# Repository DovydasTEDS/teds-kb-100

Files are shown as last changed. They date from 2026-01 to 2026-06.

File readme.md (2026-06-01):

# TEDS KB 100  
  
A 100% ISO-105 Mechanical keyboard - custom PCB, custom case.
It has per-key rgb leds and a rotary encoder. The firmware is written in QMK.

## How to build

  Flash the RP2040 / pi pico devboard with the firmware by holding the boot button and then plugging it into a computer. Then drag the firmware into a drive that appears.  
  When assembling, make sure you solder all of the components to the PCB, but don't insert the switches. First attach the plate, then add the switches into the hotswap sockets, or solder them if you choose not to include them.  
  Then screw the plate to the base, and finally, screw the top. All screws / bolts should be M3. The shorter M3 screws attach the plate to the base while the longer screws attach the top to the bottom. The top plate is optional, and it should work without it.  

## Why did I make this project?  

  Most mechanical gaming keyboards are... mediocre. Firmware that sucks. Software that sucks more. And they all lack one feature or another.  
  And many mechanical keyboards focus on... 60% and TKL. I haven't seen as much focus on cusom 100% keyboards. This is why I decided to make one! (Also since I'm using a membrane keyboard currently...)

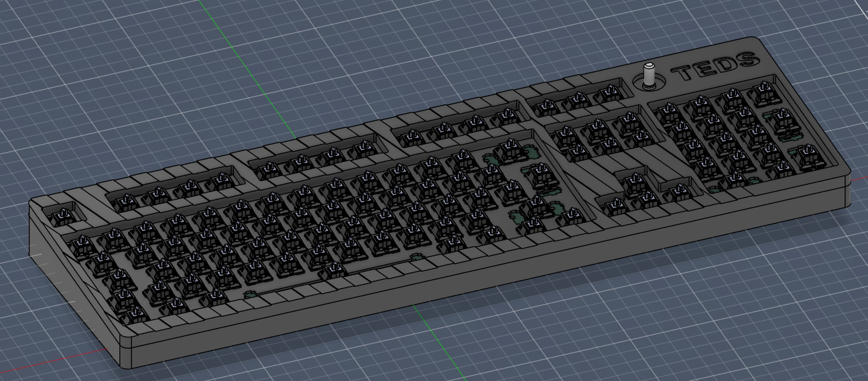
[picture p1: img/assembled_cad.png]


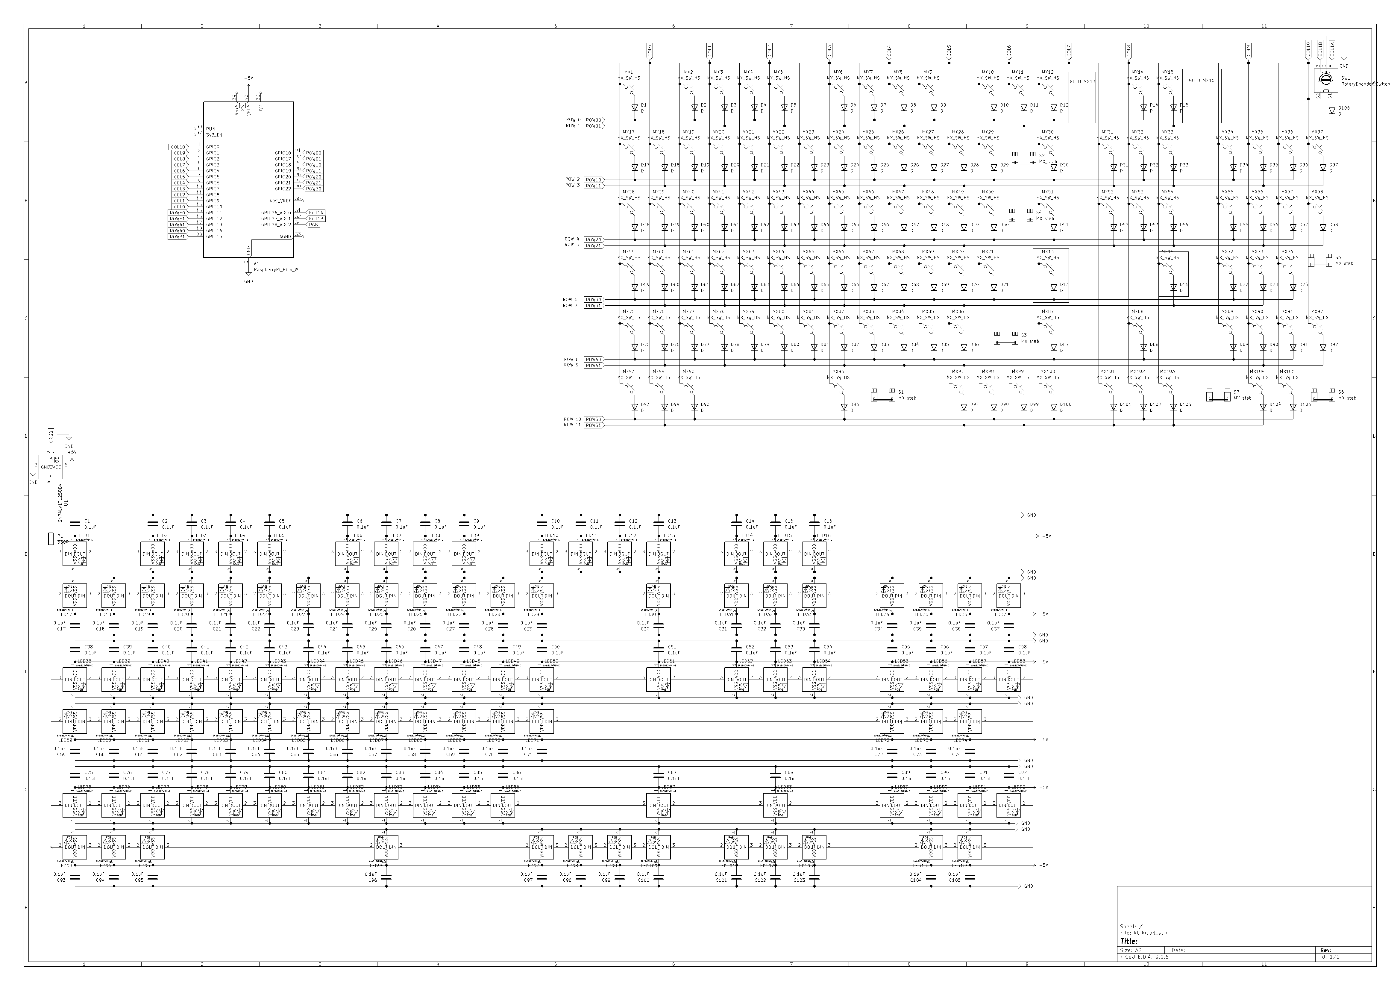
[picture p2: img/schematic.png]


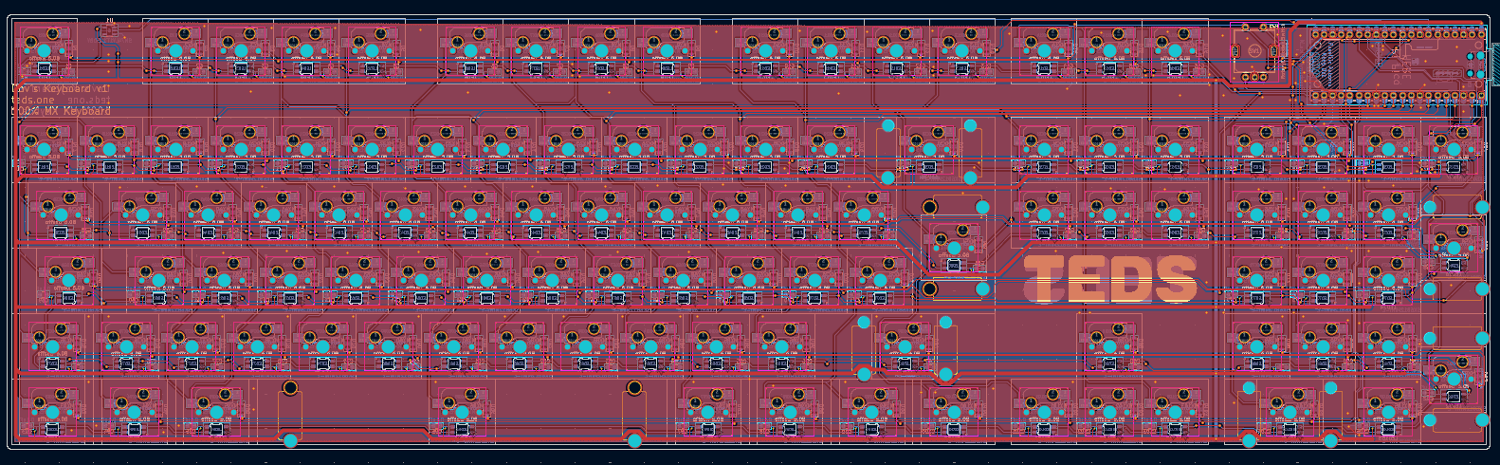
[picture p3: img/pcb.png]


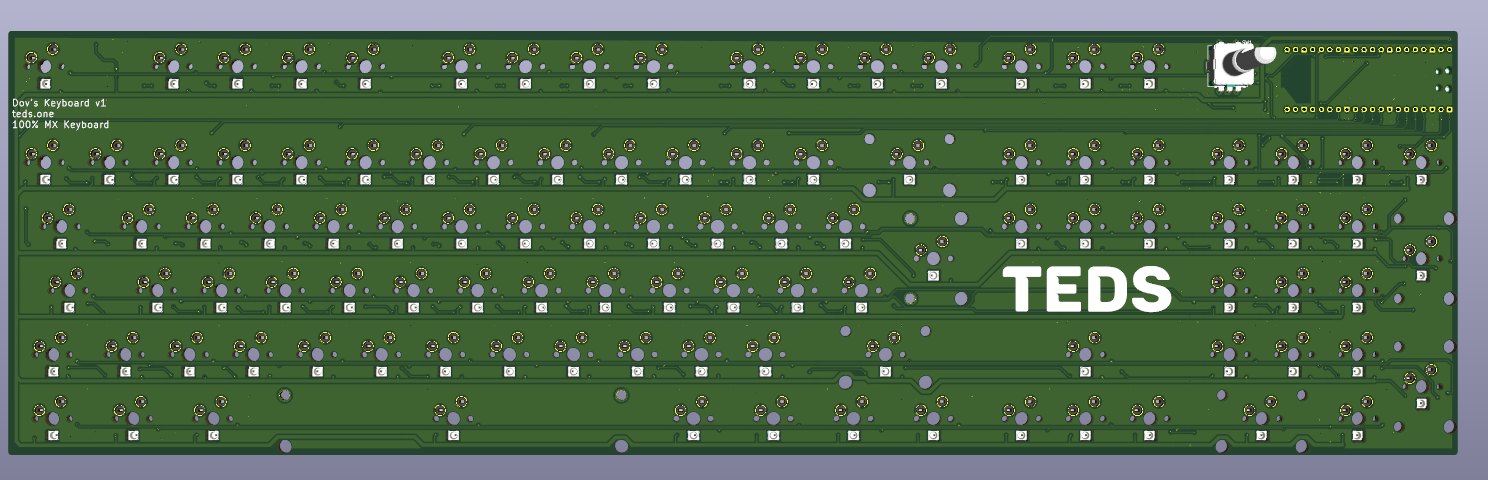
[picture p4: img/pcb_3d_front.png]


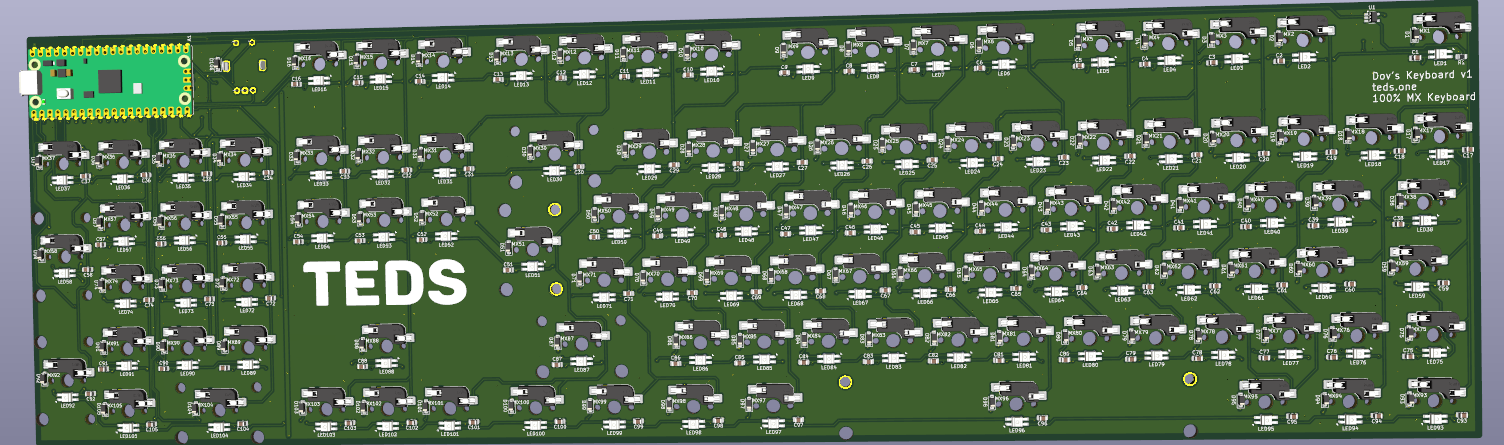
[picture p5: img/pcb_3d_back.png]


## Bill of Materials
  
|Item |Description |Quantity (no MOQ)|Amount (per quantity)|Quantity|Unit Price|Total Price|Running Total|URL |LCSC Part No|
|---|---|---|---|---|---|---|---|---|---|
|PCB |PCB (Minimum order of 5, includes $13.06 global direct line shipping, and $7.62 tax + duties)|1 |5 |1 |$45.68 |$45.68 |$45.68 |[JLCPCB](https://jlcpcb.com) | |
| | | | | | | | | | |
|LCSC |Total: 12.7692 + shipping fees | | | | | | | | |
|SK6812MINI-E |Backlight LEDs |105 |1 |105 |$0.07 |$7.27 |$52.95 |[C5149201](https://www.lcsc.com/product-detail/C5149201.html) |C5149201 |
|SN74LV1T125DBVR |Level Shifter |1 |1 |5 |$0.20 |$0.98 |$53.93 |[C473338](https://www.lcsc.com/product-detail/C473338.html) |C473338 |
|CC0805KRX7R9BB104 |100nF �10% 50V Ceramic Capacitor 0805 |105 |1 |200 |$0.01 |$1.30 |$55.23 |[C49678](https://www.lcsc.com/product-detail/C49678.html) |C49678 |
|1N4148W |Diodes Surface Mount SOD-123 |105 |1 |200 |$0.01 |$1.16 |$56.39 |[C917030](https://www.lcsc.com/product-detail/C917030.html) |C917030 |
|0805W8F3300T5E |330? �1% 125mW 0805 Thick Film Resisto |1 |1 |105 |$0.00 |$0.29 |$56.68 |[C17630](https://www.lcsc.com/product-detail/C17630.html) |C17630 |
|EC11E09244BS |Rotary Encoder EC11 |1 |1 |1 |$1.77 |$1.77 |$58.45 |[C470742](https://www.lcsc.com/product-detail/C470742.html) |C470742 |
| | | | | | | | | | |
|AliExpress |Total: 55.17 + shipping fees | | | | | | | | |
|Pi Pico Board |RP2040 Devboard / Pico Clone |1 |1 |1 |$2.73 |$2.73 |$61.18 |[AliExpress](https://www.aliexpress.com/item/1005007393927221.html)| |
|Hotswap MX Sockets|110x Kailh Hot-swappable PCB Socket Hot Plug |105 |110 |1 |$6.65 |$6.65 |$67.83 |[AliExpress](https://www.aliexpress.com/item/1005007232040760.html)| |
|Switches |Kailh Speed Sliver |105 |110 |1 |$19.41 |$19.41 |$87.24 |[AliExpress](https://www.aliexpress.com/item/1005003436102892.html)| |
|Keycaps |135 Keycaps Shine-through (Lucky Red colour) |105 |135 |1 |$13.54 |$13.54 |$100.78 |[AliExpress](https://www.aliexpress.com/item/1005010510805160.html)| |
|M3 Heatset Inserts|Length 3mm 50pcs,�M3(OD4.2mm) |18 |50 |1 |$1.87 |$1.87 |$102.65 |[AliExpress](https://www.aliexpress.com/item/1005003582355741.html)| |
|M3 Screws |M3 50pcs,�12mm |18 |50 |1 |$1.87 |$1.87 |$104.52 |[AliExpress](https://www.aliexpress.com/item/1005007264845313.html)| |
|Stabilisers |Durock Stabilisers V3 BS 7x2u 1x6.25u |1 |1 |1 |$6.74 |$6.74 |$111.26 |[AliExpress](https://www.aliexpress.com/item/1005006528731543.html)| |
|Encoder Knob |Red Enoder Knob |1 |1 |1 |$2.36 |$2.36 |$113.62 |[AliExpress](https://www.aliexpress.com/item/1005009263732468.html)| |
| | | | | | | | | | |
| | | | | | |Total: |$113.62 | | |

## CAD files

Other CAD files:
cad/step/Top.step
production/Bottom.step
cad/step/Plate.step
production/Top.step
cad/step/Bottom.step
production/Plate.step
cad/f3d/Assembled.f3z
cad/f3d/Bottom.f3d
cad/f3d/Plate.f3d
cad/f3d/Top.f3d

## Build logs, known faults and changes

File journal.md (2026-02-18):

<!--
  This journal is auto generated by Hack Club Blueprint.
-->

# 12/29/2025 - Layout + Switches  

_Time spent: 3.0h_  




First, I setup the required KiCad libraries / plugins. This involved installing the following repos:
[Zykrah's KiCad repository](https://raw.githubusercontent.com/zykrah/zykrah-kicad-repository/main/repository.json)
[ebastler KiCad repository](https://raw.githubusercontent.com/ebastler/ebastler-KiCad-repository/main/repository.json)

From these repos, I installed the marbastlib library and the KiCad KLE placer plugin.

I then started placing down the switch matrix (22 columns, 6 rows). I then deleted the switches that weren't used, or areas where a switch was larger (e.g. enter, shift). After that, I started placing the PCB. After updating from the schematic, I placed the first switch and diode down in their correct positions. Using the KLE auto placer plugin, I was able to easily replicate this and place all of the other switches down, with the diodes in the same position. I then placed all of the stabilisers for all of the switches that were 2u or larger.

Summary:  
- Setup the environment
- Created the schematic for the switch matrix
- Placed switches in ISO 105 key layout
- Placed stabilisers

Todo:
- Wire everything
- Add leds (per switch)  

# 1/10/2026 10 AM - Connected switches (Schematic)  

_Time spent: 0.5h_  



I connected all of the switches in the schematic in a matrix. I ended up with 6 rows and 20 columns. Unfortunately the pico only has 26 GPIO pins. I may need to use an IO expander.  

# 1/10/2026 3 PM - Duplex Matrix  

_Time spent: 1.0h_  



Instead of an IO expander, I decided to add a duplex matrix. This involved merging 2 pairs of columns, halving the number of columns needed, but doubling the rows needed. Overall, this saved pins. I was also able to move some of the switches which were in a column alone to free up a column. This should remove the need for an IO expander. I looked into IO expanders, but felt they were too undocumented, both in QMK and ZMK. I am also considering whether I should add a rotary encoder or an oled screen, since I will only have 2 free GPIO pins after I add the backlight / rgb lights.  

# 1/11/2026 10:04 PM - Added RGB  

_Time spent: 2.0h_  



I added the RGB leds (sk6812mini-e) to the schematic and wired them up. I used 0.1uF capacitors to reduce the power consumption and that it wouldn't overload the pi. I connected the 5v to the VBUS / USB 5v power. Hopefully it works. Also wasted a bit of time due to bad counting.   

# 1/11/2026 10:24 PM - Fixed Capacitors  

_Time spent: 0.5h_  



So turns out I don't know how capacitors work... At least I figured it out by doing some googling and wondering why mine looks very different to the others.  

# 1/12/2026 - Position all LEDs  

_Time spent: 2.0h_  



I positioned all of the SK6812MINI-E LEDs and started wiring up the switches. But guess who forgot the capacitors... me. Hopefully all of the traces arent in the way of the capacitors.  

# 1/14/2026 - Capacitors + Connect rows + Columns  

_Time spent: 2.0h_  



I connected all of the rows and columns together (duplex so 2x rows and half columns). I placed the capacitors after which was a bad idea, but in the end it worked out. It was a lot of clicking and SHIFT + P. I used the (-7.4, 4) and (7.4, 6) offsets for the left and right capacitors. This is because I ended up flipping half of the LEDs to make data connections easier as it is in a Z pattern, going from left to right in the top row, right to left in the row below and so on.


# 1/16/2026 - Routed 5v + Capacitors  

_Time spent: 3.5h_  



I routed all of the LED 5v pads to the capacitors, then connected the lines to a large 5v running throughout the board. The main 5v trace is thicker to prevent issues.
I also routed all of the columns, and started work on the rows and connecting the LEDs.  

# 1/17/2026 - Finished PCB (I think / hope)  

_Time spent: 3.0h_  



Everything is routed. I routed the columns and rows to the Pi Pico. Was a struggle especially with all of the traces being packed together tightly. I then added a ground fill, and fixed any errors. I then added a silkscreen. I will now need to design a case, and also make the firmware.  

# 1/19/2026 - Added a level shifter.  

_Time spent: 0.2h_  



Why? Some guy in some random discord server told me to. Yep. That's it. I had a look around at different level shifters and figured out this one isn't too big and might not be too hard to solder.

  

I was also given the advice to use a lower power LED but... I decided to stick with these. Resistors should make it fine and I can always limit it in QMK. I think.  

# 1/25/2026 12 PM - Created Keyboard Plate  

_Time spent: 2.0h_  



I used a generator to create the plate DXF. I added extra padding to ensure there is enough space and then added screw holes / tabs. I decided to go with a bottom mount instead of a tray mount.  

# 1/25/2026 4 PM - Created (mostly) bottom part of the case  

_Time spent: 2.5h_  



Using a sketch of the plate, I made the bottom case. I added a 1mm tolerence for the plate / case so that it would fit. I used an MX switch where the ESC key would be to align the plate and PCB. 



At first there was less clearance but then I added a bit more to make sure a USBC pico clone could fit (might use my RP2040 devboard that I made)  

# 1/25/2026 6 PM - Placed switches + Adapted plate to better fit rotary encoder  

_Time spent: 1.0h_  

Assembled

I placed every single MX switch into their spots. I used the measure tool and used move / copy along with coordinates to correctly place every single switch. I then edited the plate to add a square hole for the rotary encoder with a 0.5mm tolerance on all 4 sides.  

# 1/26/2026 - Redid plate + bottom placement / support  

_Time spent: 2.0h_  


I felt that the old plate + bottom case didn't support the case well and may break. As a result, I redid how it worked. Would've been quicker if fusion wasn't annoying and / or I did it from the start, but here I am. Time to work on the top part!  

# 1/27/2026 - Finished Top Case  

_Time spent: 4.0h_  

AssembledKB

I created the top case. First, I added screw holes to the bottom case. To do this, I had to adjust the mounting tabs to make enough space and to ensure it is strong enough.


Here is the top case:


I added space for an 18mm rotary encoder knob.



I also added some extra space for the tabs. 1.5mm extra so that a 3mm (1.5mm) acrylic plate could be used if needed, and an extra 3mm to make clearance for the M3 screws / bolts securing the plate to the bottom case.



I also added a tilt to the bottom of the case


It should be around 5 degrees.

I also added a hole / slot for a USB cable (hopefully USBC if I can get a USBC RP2040 board)


I definitely didn't spend all day on this...
Time to get ready for the Design Review! (readme in repo, add cad files, bill of material etc.)

# 2/17/2026 - Added screws + heatset inserts  

_Time spent: 1.0h_  



I added all of the heatset inserts and screws inside the assembled CAD. This will help me better plan / design the case, as well as any spacing / tolerances.  

# 2/18/2026 - Updated Case Design  

_Time spent: 2.0h_  



I added a sort of textured design to the front plate, as well as the TEDS logo. This adds some feel and texture to the keyboard, and makes it seem less flat. I also slightly reinforced some of the holes where the heat sets would go into in the bottom.


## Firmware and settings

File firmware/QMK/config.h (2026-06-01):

/*
Copyright 2026 DovydasTEDS

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
You should have received a copy of the GNU General Public License
along with this program.  If not, see <http://www.gnu.org/licenses/>.*/

#pragma once

#define ENCODER_A_PINS { GP26 }
#define ENCODER_B_PINS { GP27 }

#define WS2812_DI_PIN GP28

#define RGB_MATRIX_LED_COUNT 105
#define WS2812_BYTE_ORDER WS2812_BYTE_ORDER_GRB

#define RGB_MATRIX_MAXIMUM_BRIGHTNESS 95

#define RGB_MATRIX_SLEEP

// #define LAYER_INDICATOR_LED_INDEX 0

#define NUMLOCK_INDICATOR_LED_INDEX 19
#define CAPSLOCK_INDICATOR_LED_INDEX 73
#define SCROLLLOCK_INDICATOR_LED_INDEX 14

#define RGB_MATRIX_INDICATOR_ENABLE

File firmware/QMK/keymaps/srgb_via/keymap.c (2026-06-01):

/*
Copyright 2026 DovydasTEDS

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
You should have received a copy of the GNU General Public License
along with this program.  If not, see <http://www.gnu.org/licenses/>.*/

// #include QMK_KEYBOARD_H
// #if __has_include("keymap.h")
// #    include "keymap.h"
// #endif

// Tap dance enums
enum {
    TD_ENCODER,  // Double tap to skip
};

// Tap dance actions
tap_dance_action_t tap_dance_actions[] = {
    [TD_ENCODER] = ACTION_TAP_DANCE_DOUBLE(KC_MPLY, KC_MNXT),  // Double tap = skip song
};

/* THIS FILE WAS GENERATED!
 *
 * This file was generated by qmk json2c. You may or may not want to
 * edit it directly.
 */

const uint16_t PROGMEM keymaps[][MATRIX_ROWS][MATRIX_COLS] = {
    [0] = LAYOUT(
        KC_ESC  , KC_F1   , KC_F2   , KC_F3   , KC_F4   , KC_F5   , KC_F6   , KC_F7   , KC_F8   , KC_F9   , KC_F10  , KC_F11  , KC_F12  ,                   KC_PSCR , KC_SCRL , KC_PAUS ,       TD(TD_ENCODER) ,
        KC_GRV  , KC_1    , KC_2    , KC_3    , KC_4    , KC_5    , KC_6    , KC_7    , KC_8    , KC_9    , KC_0    , KC_MINS , KC_EQL  , KC_BSPC ,         KC_INS  , KC_HOME , KC_PGUP ,       KC_NUM  , KC_PSLS , KC_PAST , KC_PMNS ,
        KC_TAB  , KC_Q    , KC_W    , KC_E    , KC_R    , KC_T    , KC_Y    , KC_U    , KC_I    , KC_O    , KC_P    , KC_LBRC , KC_RBRC , KC_ENT  ,         KC_DEL  , KC_END  , KC_PGDN ,       KC_P7   , KC_P8   , KC_P9   , KC_PPLS ,
        KC_CAPS , KC_A    , KC_S    , KC_D    , KC_F    , KC_G    , KC_H    , KC_J    , KC_K    , KC_L    , KC_SCLN , KC_QUOT , KC_NUHS ,                                                       KC_P4   , KC_P5   , KC_P6   ,
        KC_LSFT , KC_NUBS , KC_Z    , KC_X    , KC_C    , KC_V    , KC_B    , KC_N    , KC_M    , KC_COMM , KC_DOT  , KC_SLSH ,     KC_RSFT ,                         KC_UP   ,                 KC_P1   , KC_P2   , KC_P3   , KC_PENT ,
        KC_LCTL , KC_LGUI , KC_LALT ,                               KC_SPC  ,                               KC_RALT , KC_RGUI , KC_APP  , KC_RCTL ,         KC_LEFT , KC_DOWN , KC_RGHT ,       KC_P0   , KC_PDOT
    ),
    [1] = LAYOUT(
        KC_ESC  , KC_F1   , KC_F2   , KC_F3   , KC_F4   , KC_F5   , KC_F6   , KC_F7   , KC_F8   , KC_F9   , KC_F10  , KC_F11  , KC_F12  ,                   KC_PSCR , KC_SCRL , KC_PAUS ,       TD(TD_ENCODER) ,
        KC_GRV  , KC_1    , KC_2    , KC_3    , KC_4    , KC_5    , KC_6    , KC_7    , KC_8    , KC_9    , KC_0    , KC_MINS , KC_EQL  , KC_BSPC ,         KC_INS  , KC_HOME , KC_PGUP ,       KC_NUM  , KC_PSLS , KC_PAST , KC_PMNS ,
        KC_TAB  , KC_Q    , KC_W    , KC_E    , KC_R    , KC_T    , KC_Y    , KC_U    , KC_I    , KC_O    , KC_P    , KC_LBRC , KC_RBRC , KC_ENT  ,         KC_DEL  , KC_END  , KC_PGDN ,       KC_P7   , KC_P8   , KC_P9   , KC_PPLS ,
        KC_CAPS , KC_A    , KC_S    , KC_D    , KC_F    , KC_G    , KC_H    , KC_J    , KC_K    , KC_L    , KC_SCLN , KC_QUOT , KC_NUHS ,                                                       KC_P4   , KC_P5   , KC_P6   ,
        KC_LSFT , KC_NUBS , KC_Z    , KC_X    , KC_C    , KC_V    , KC_B    , KC_N    , KC_M    , KC_COMM , KC_DOT  , KC_SLSH ,     KC_RSFT ,                         KC_UP   ,                 KC_P1   , KC_P2   , KC_P3   , KC_PENT ,
        KC_LCTL , KC_LGUI , KC_LALT ,                               KC_SPC  ,                               KC_RALT , KC_RGUI , KC_APP  , KC_RCTL ,         KC_LEFT , KC_DOWN , KC_RGHT ,       KC_P0   , KC_PDOT
    ),
    [2] = LAYOUT(
        KC_ESC  , KC_F1   , KC_F2   , KC_F3   , KC_F4   , KC_F5   , KC_F6   , KC_F7   , KC_F8   , KC_F9   , KC_F10  , KC_F11  , KC_F12  ,                   KC_PSCR , KC_SCRL , KC_PAUS ,       TD(TD_ENCODER) ,
        KC_GRV  , KC_1    , KC_2    , KC_3    , KC_4    , KC_5    , KC_6    , KC_7    , KC_8    , KC_9    , KC_0    , KC_MINS , KC_EQL  , KC_BSPC ,         KC_INS  , KC_HOME , KC_PGUP ,       KC_NUM  , KC_PSLS , KC_PAST , KC_PMNS ,
        KC_TAB  , KC_Q    , KC_W    , KC_E    , KC_R    , KC_T    , KC_Y    , KC_U    , KC_I    , KC_O    , KC_P    , KC_LBRC , KC_RBRC , KC_ENT  ,         KC_DEL  , KC_END  , KC_PGDN ,       KC_P7   , KC_P8   , KC_P9   , KC_PPLS ,
        KC_CAPS , KC_A    , KC_S    , KC_D    , KC_F    , KC_G    , KC_H    , KC_J    , KC_K    , KC_L    , KC_SCLN , KC_QUOT , KC_NUHS ,                                                       KC_P4   , KC_P5   , KC_P6   ,
        KC_LSFT , KC_NUBS , KC_Z    , KC_X    , KC_C    , KC_V    , KC_B    , KC_N    , KC_M    , KC_COMM , KC_DOT  , KC_SLSH ,     KC_RSFT ,                         KC_UP   ,                 KC_P1   , KC_P2   , KC_P3   , KC_PENT ,
        KC_LCTL , KC_LGUI , KC_LALT ,                               KC_SPC  ,                               KC_RALT , KC_RGUI , KC_APP  , KC_RCTL ,         KC_LEFT , KC_DOWN , KC_RGHT ,       KC_P0   , KC_PDOT
    )
    
};




// #ifdef OTHER_KEYMAP_C
// #    include OTHER_KEYMAP_C
// #endif // OTHER_KEYMAP_C

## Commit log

2026-01-17 create repo
    [kb.kicad_sch]
2026-01-19 add level shifter
    [kb.kicad_sch]
2026-01-26 fix (w commit message)
    [config.h, keymap.c]
2026-01-28 Finalise PCB + Add PCB production files
    [kb.kicad_sch]
2026-01-30 upload cad
    [Bottom.f3d, Bottom.step, Plate.f3d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]
2026-01-30 add production files
    [Bottom.step, Plate.step, Top.step]
2026-01-30 add bill of materials
    [BOM.csv]
2026-01-30 update pcb files
    [kb.kicad_sch]
2026-01-30 Update BOM
    [BOM.csv]
2026-01-30 add assembled step
    [Assembled (No PCB, No Switches).step]
2026-01-31 mark encoder properly (no new build since minor change + new firmware is wip)
2026-02-15 Add reviewer note to readme
    Added important note for reviewer regarding case edits and 3D printing.
2026-02-15 Update README with Fusion archive information
    Added a note about including a Fusion archive for the PCB export issue.
2026-02-18 Update case
    [Assembled (No PCB, No Switches).step, Assembled.f3z, Bottom.f3d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]
2026-02-18 Update case 2
    [Bottom.step, Top.step]
2026-06-01 fix readme bom
2026-06-01 fix bom wording
    [BOM.csv]
2026-09-07 update journal - latest from blueprint
    includes assembly + assembled keyboard

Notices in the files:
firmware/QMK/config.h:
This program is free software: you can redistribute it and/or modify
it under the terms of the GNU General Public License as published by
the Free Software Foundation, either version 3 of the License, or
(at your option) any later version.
